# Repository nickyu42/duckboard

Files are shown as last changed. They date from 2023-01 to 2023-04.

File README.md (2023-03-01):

# Duckboard

This repository contains the PCB design for a 4x4 macroboard with a rotary encoder.  





## Fusion360 Model and Case





## Schematic



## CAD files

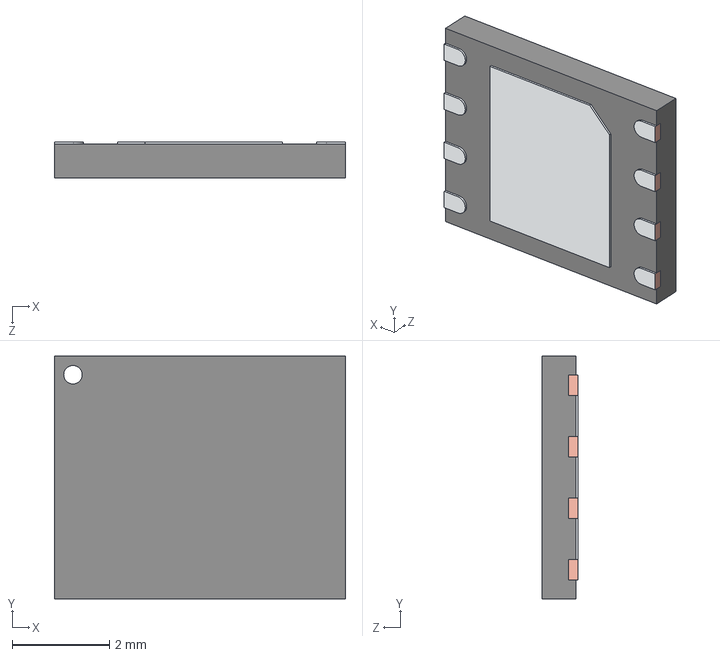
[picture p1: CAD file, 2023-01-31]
pcb/3D/User Library-8 WSON.STEP
6.00 x 5.00 x 0.75 mm

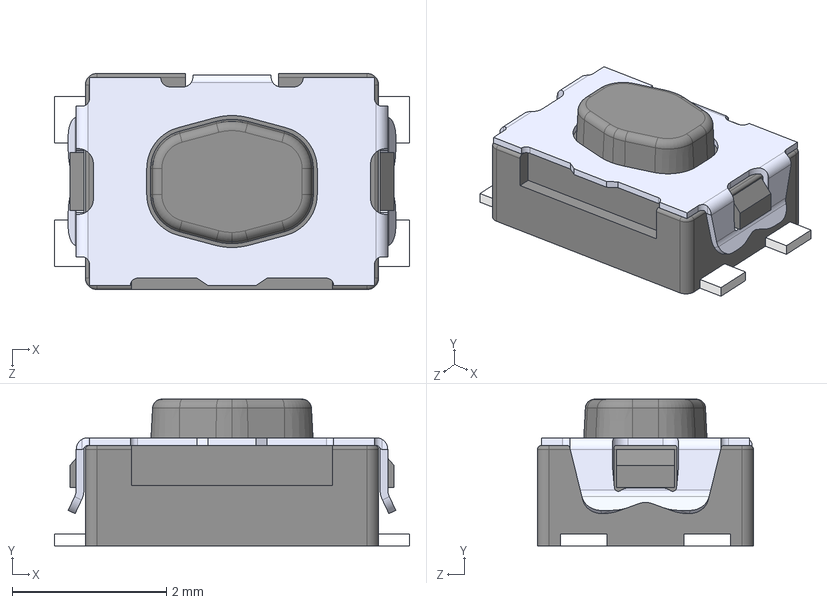
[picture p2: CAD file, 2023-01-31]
pcb/footprints/KMR221GLFS/KMR221GLFS.step
4.60 x 1.90 x 2.80 mm

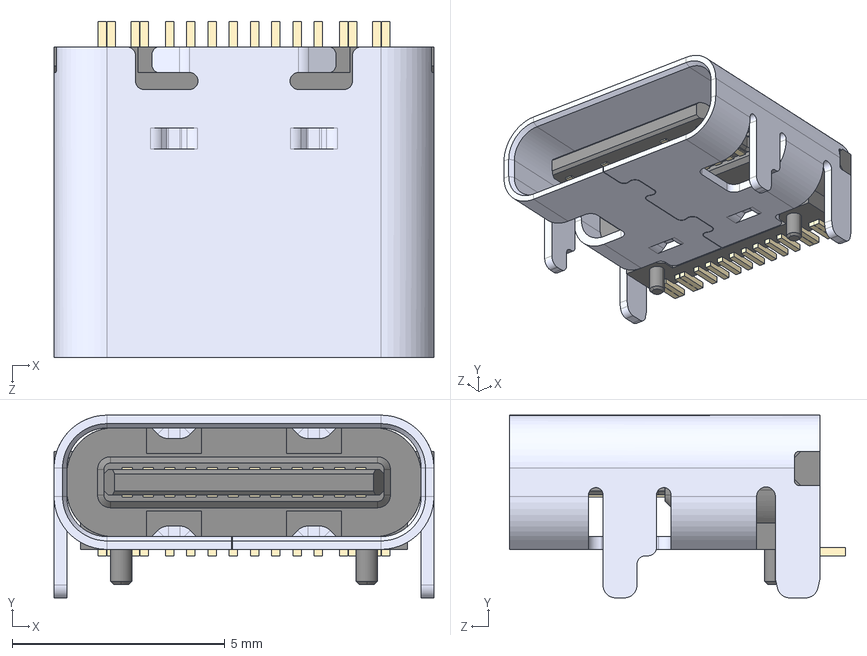
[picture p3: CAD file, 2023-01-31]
pcb/footprints/TYPE-C-31-M-12/TYPE-C-31-M-12.step
8.94 x 4.30 x 7.90 mm

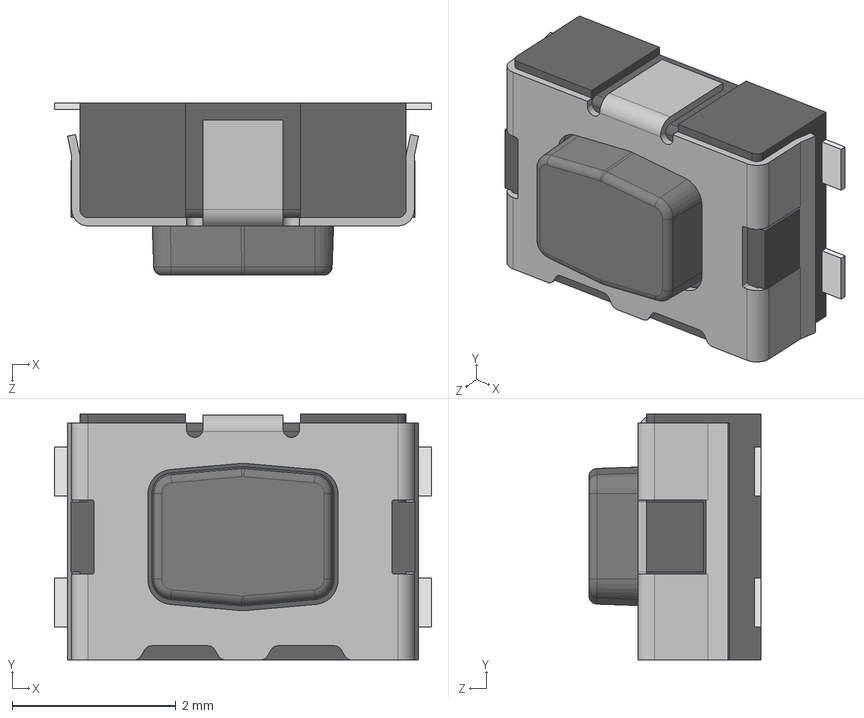
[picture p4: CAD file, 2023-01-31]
pcb/3D/Switch-CK-KMR2.STEP
4.60 x 3.00 x 2.10 mm
Button
Boitier
Tole
Pads

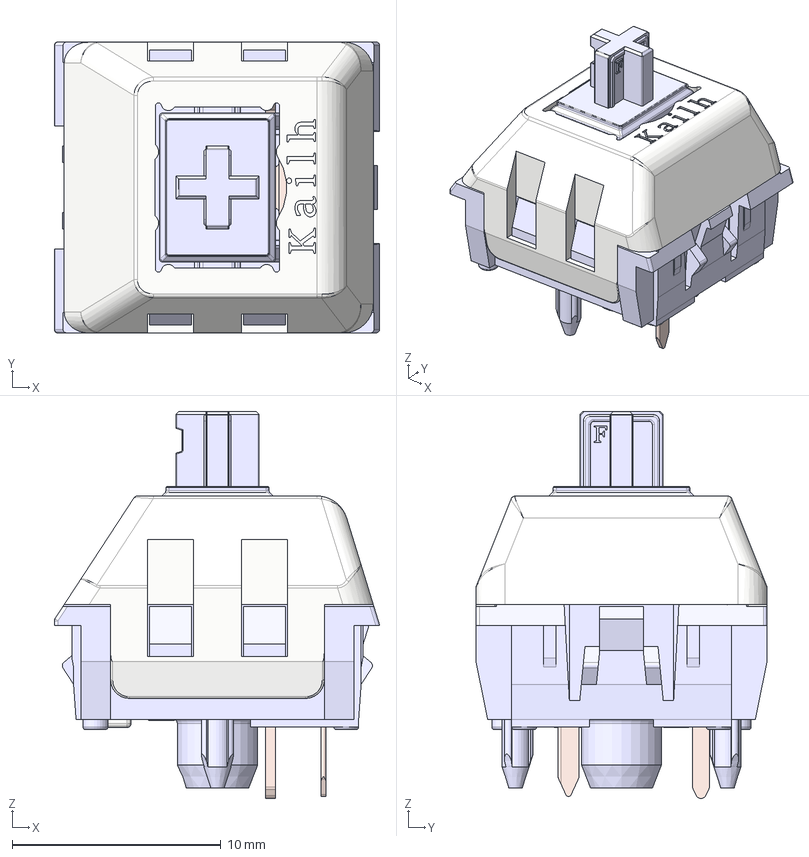
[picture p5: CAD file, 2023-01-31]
pcb/3D/Kailh Polia.step
15.6 x 14.0 x 18.5 mm
Housing
ThickContact
SpringContact
Stem
Lid

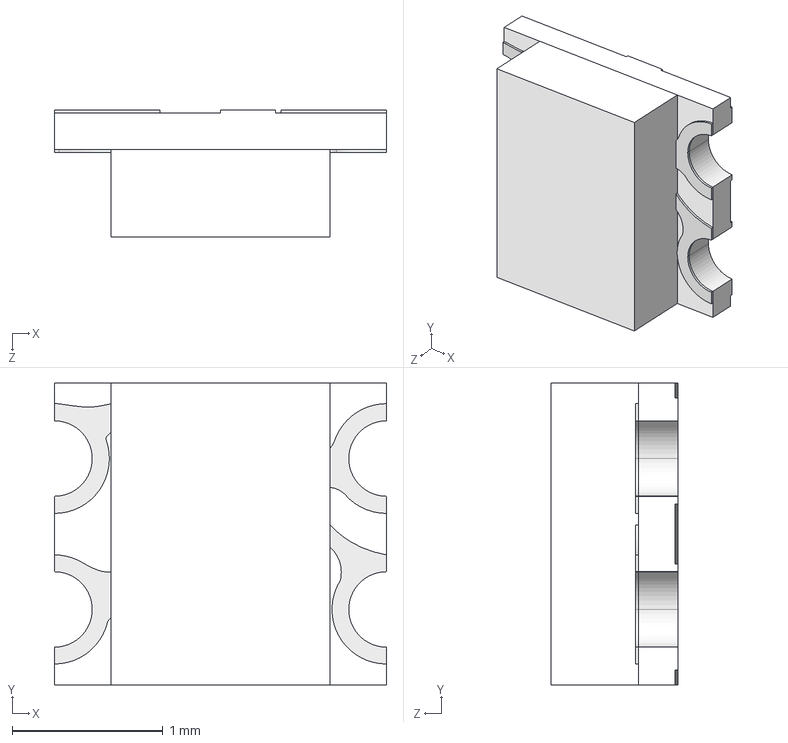
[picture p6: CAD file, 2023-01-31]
pcb/3D/User Library-WS2812-2020.STEP
2.20 x 2.00 x 0.84 mm

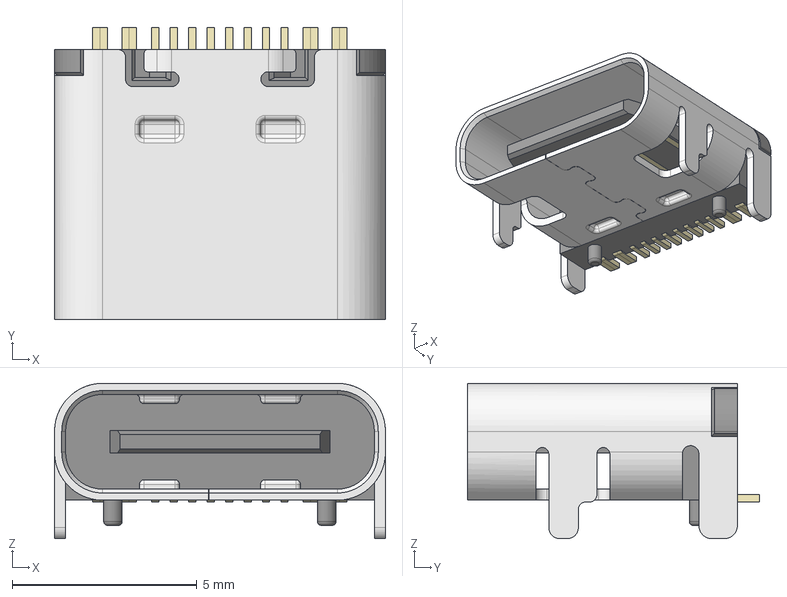
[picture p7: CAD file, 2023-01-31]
pcb/3D/HRO_TYPE-C-31-M-12.step
8.95 x 7.90 x 4.20 mm

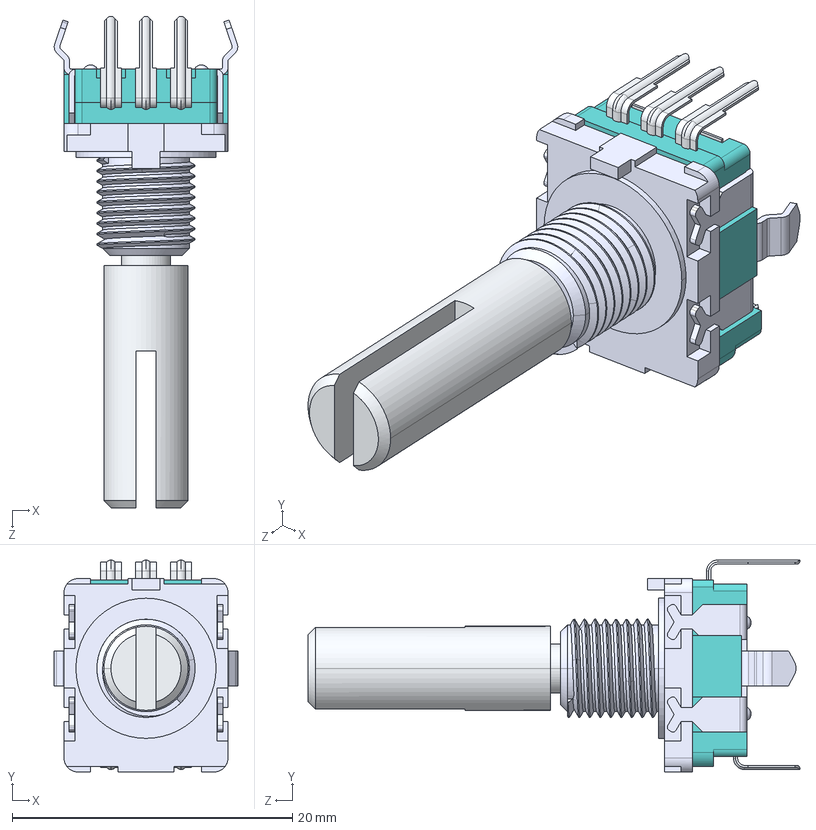
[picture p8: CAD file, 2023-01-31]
pcb/3D/User Library-EC11B15244.STEP
13.1 x 15.1 x 35.1 mm
Shaft
MetalBody
PlasticBody
Imported x 3
Pin x 2
Sheet Metal Part53

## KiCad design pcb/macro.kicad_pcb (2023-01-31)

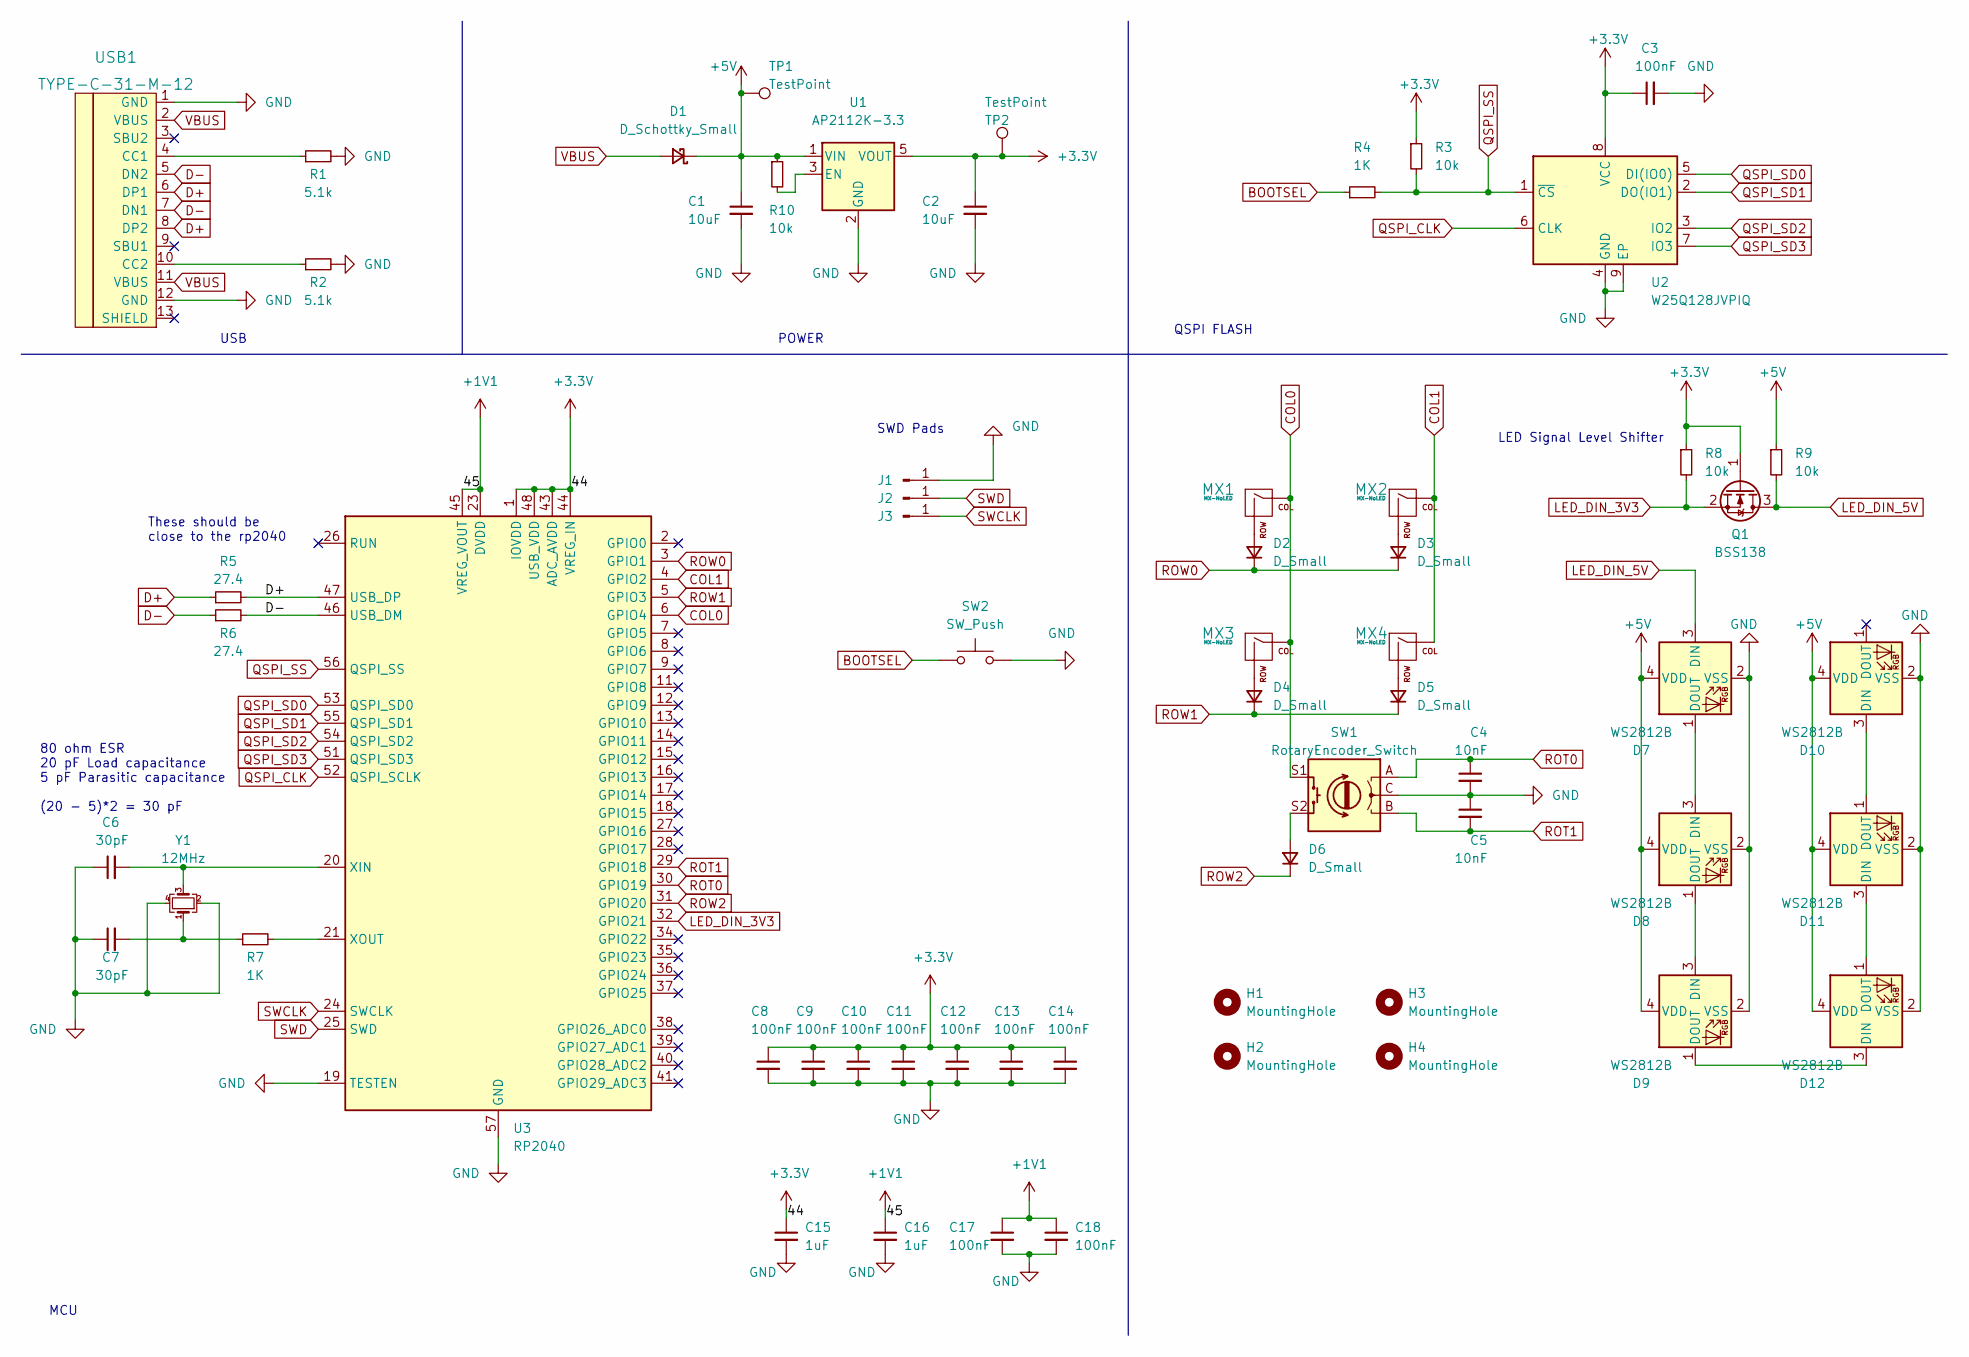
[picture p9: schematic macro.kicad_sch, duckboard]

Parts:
C1, C2: 10uF; C_0402_1005Metric
C3, C8, C9, C10, C11, C12, C13, C14, C17, C18: 100nF; C_0402_1005Metric
C4, C5: 10nF; C_0402_1005Metric
C6, C7: 30pF; C_0402_1005Metric
C15, C16: 1uF; C_0402_1005Metric
D1: D_Schottky_Small; D_SOD-323
D2, D3, D4, D5, D6: D_Small; D_SOD-323
D7, D8, D9, D10, D11, D12: WS2812B; LED_WS2812B-2020_PLCC4_2.0x2.0mm
H1, H2, H3, H4: MountingHole; MountingHole_2.2mm_M2
J1, J2, J3: Conn_01x01_Male; TestPoint_Pad_2.0x2.0mm
MX1, MX2, MX3, MX4: MX-NoLED; MX-1U-NoLED
Q1: BSS138; SOT-23
R1, R2: 5.1k; R_0402_1005Metric
R3, R8, R9, R10: 10k; R_0402_1005Metric
R4, R7: 1K; R_0402_1005Metric
R5, R6: 27.4; R_0402_1005Metric
SW1: RotaryEncoder_Switch; RotaryEncoder_Alps_EC11E-Switch_Vertical_H20mm_CircularMoun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
SW2: SW_Push; SW_KMR221GLFS
TP1, TP2: TestPoint; TestPoint_Pad_D1.0mm
U1: AP2112K-3.3; SOT-23-5
U2: W25Q128JVPIQ; WSON-8-1EP_6x5mm_P1.27mm_EP3.4x4.3mm
U3: RP2040; QFN-56-1EP_7x7mm_P0.4mm_EP3.2x3.2mm
USB1: TYPE-C-31-M-12; HRO_TYPE-C-31-M-12
Y1: 12MHz; Crystal_SMD_3225-4Pin_3.2x2.5mm

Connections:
+1V1: C16.1, C17.1, C18.1, U3.23 (DVDD), U3.45 (VREG_VOUT), U3.50 (DVDD)
+3.3V: C2.1, C3.1, C8.1, C9.1, C10.1, C11.1, C12.1, C13.1, C14.1, C15.1, Q1.1 (G), R3.1, R8.1, TP2.1, U1.5 (VOUT), U2.8 (VCC), U3.1 (IOVDD), U3.10 (IOVDD), U3.22 (IOVDD), U3.33 (IOVDD), U3.42 (IOVDD), U3.43 (ADC_AVDD), U3.44 (VREG_IN), U3.48 (USB_VDD), U3.49 (IOVDD)
+5V: C1.1, D1.1 (K), D7.4 (VDD), D8.4 (VDD), D9.4 (VDD), D10.4 (VDD), D11.4 (VDD), D12.4 (VDD), R9.1, R10.1, TP1.1, U1.1 (VIN)
BOOTSEL: R4.1, SW2.1
COL0: MX1.1 (COL), MX3.1 (COL), SW1.S1, U3.6 (GPIO4)
COL1: MX2.1 (COL), MX4.1 (COL), U3.4 (GPIO2)
D+: R5.1, R5.2, U3.47 (USB_DP), USB1.6 (DP1), USB1.8 (DP2)
D-: R6.1, R6.2, U3.46 (USB_DM), USB1.5 (DN2), USB1.7 (DN1)
GND: C1.2, C2.2, C3.2, C4.2, C5.1, C6.1, C7.1, C8.2, C9.2, C10.2, C11.2, C12.2, C13.2, C14.2, C15.2, C16.2, C17.2, C18.2, D7.2 (VSS), D8.2 (VSS), D9.2 (VSS), D10.2 (VSS), D11.2 (VSS), D12.2 (VSS), J1.1, R1.2, R2.2, SW1.C, SW2.2, SW2.5, U1.2 (GND), U2.4 (GND), U2.9 (EP), U3.19 (TESTEN), U3.57 (GND), USB1.1 (GND), USB1.12 (GND), Y1.2, Y1.4
LED_DIN_3V3: Q1.2 (S), R8.2, U3.32 (GPIO21)
LED_DIN_5V: D7.3 (DIN), Q1.3 (D), R9.2
unnamed: C6.2, U3.20 (XIN), Y1.3
unnamed: C7.2, R7.1, Y1.1
unnamed: D2.2 (A), MX1.2 (ROW)
unnamed: D3.2 (A), MX2.2 (ROW)
unnamed: D4.2 (A), MX3.2 (ROW)
unnamed: D5.2 (A), MX4.2 (ROW)
unnamed: D6.2 (A), SW1.S2
unnamed: D7.1 (DOUT), D8.3 (DIN)
unnamed: D8.1 (DOUT), D9.3 (DIN)
unnamed: D10.3 (DIN), D11.1 (DOUT)
unnamed: D11.3 (DIN), D12.1 (DOUT)
unnamed: D9.1 (DOUT), D12.3 (DIN)
unnamed: R1.1, USB1.4 (CC1)
unnamed: R2.1, USB1.10 (CC2)
unnamed: R7.2, U3.21 (XOUT)
unnamed: R10.2, U1.3 (EN)
QSPI_CLK: U2.6 (CLK), U3.52 (QSPI_SCLK)
QSPI_SD0: U2.5 (DI(IO0)), U3.53 (QSPI_SD0)
QSPI_SD1: U2.2 (DO(IO1)), U3.55 (QSPI_SD1)
QSPI_SD2: U2.3 (IO2), U3.54 (QSPI_SD2)
QSPI_SD3: U2.7 (IO3), U3.51 (QSPI_SD3)
QSPI_SS: R3.2, R4.2, U2.1 (~CS), U3.56 (QSPI_SS)
ROT0: C4.1, SW1.A, U3.30 (GPIO19)
ROT1: C5.2, SW1.B, U3.29 (GPIO18)
ROW0: D2.1 (K), D3.1 (K), U3.3 (GPIO1)
ROW1: D4.1 (K), D5.1 (K), U3.5 (GPIO3)
ROW2: D6.1 (K), U3.31 (GPIO20)
SWCLK: J3.1, U3.24 (SWCLK)
SWD: J2.1, U3.25 (SWD)
VBUS: D1.2 (A), USB1.2 (VBUS), USB1.11 (VBUS)

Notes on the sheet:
These should be close to the rp2040
LED Signal Level Shifter
SWD Pads
80 ohm ESR 20 pF Load capacitance 5 pF Parasitic capacitance (20 - 5)*2 = 30 pF
POWER
QSPI FLASH
USB
MCU

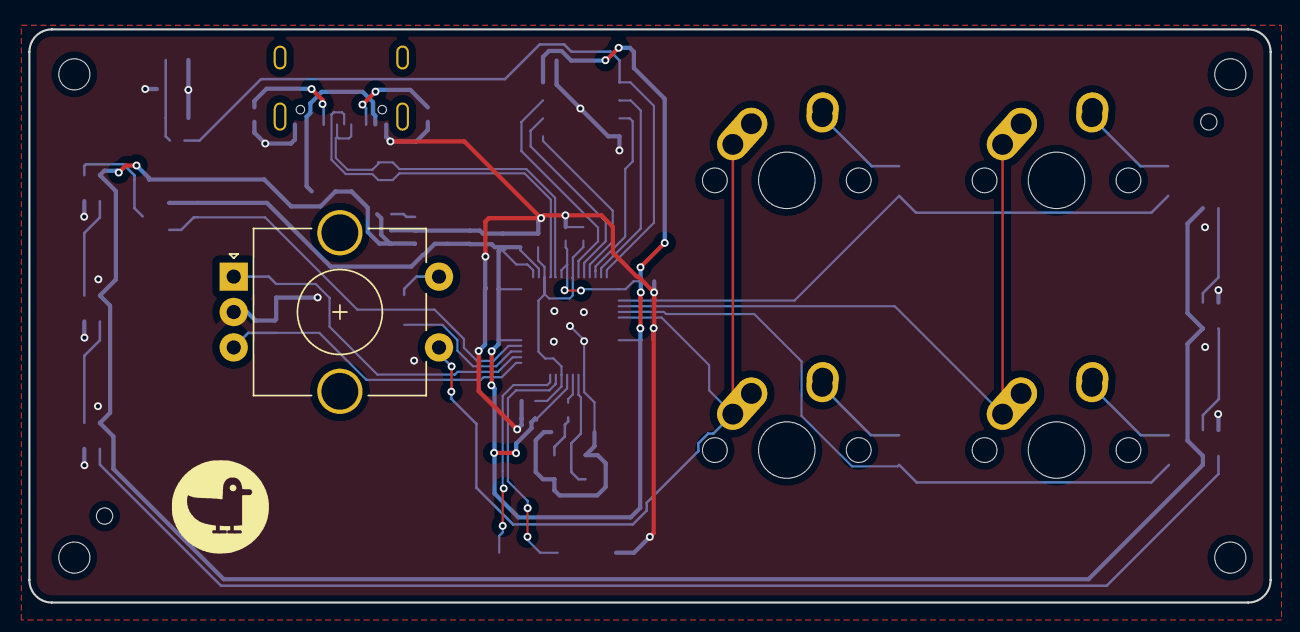
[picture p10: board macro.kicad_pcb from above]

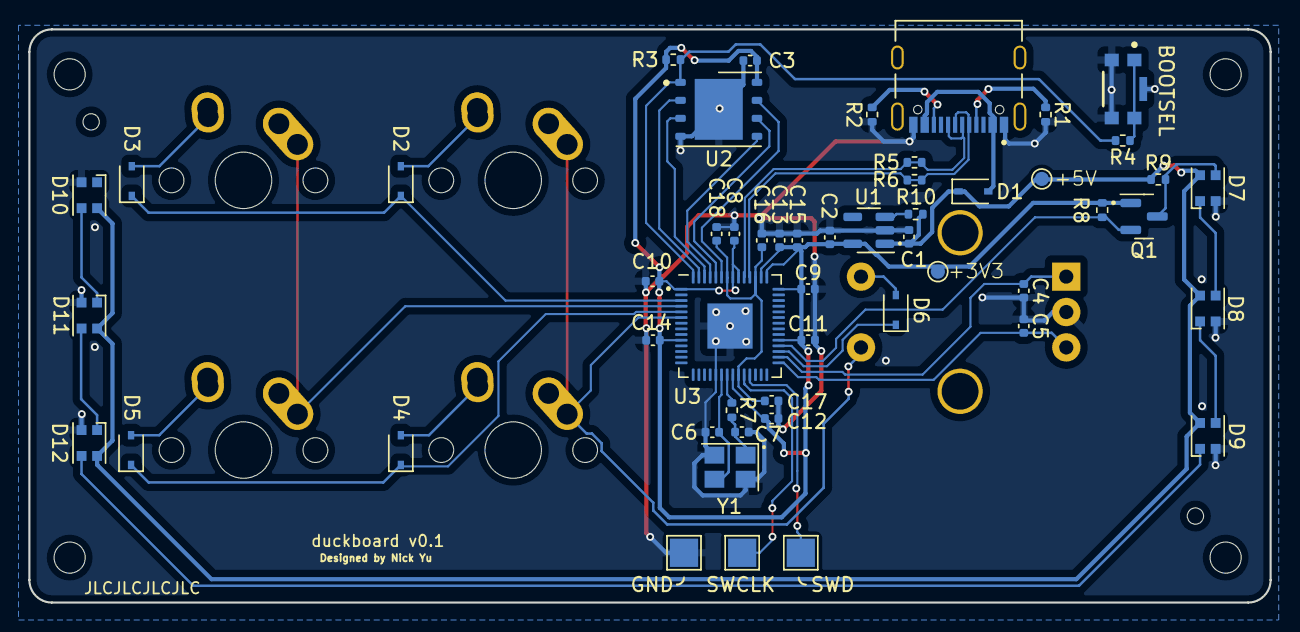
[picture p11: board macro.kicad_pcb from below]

Board: 2 copper layers, 87.7 x 40.5 mm, 61 parts (52 on the bottom side), 41 nets.

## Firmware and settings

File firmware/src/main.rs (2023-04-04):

#![no_std]
#![no_main]
#![feature(let_chains)]

// Handle panicking with probe-run
use panic_probe as _;

use rtic;

mod board_config;
mod key_mapping;
mod keyboard_matrix;
mod rotary_encoder;

#[rtic::app(device = rp2040_hal::pac, peripherals = true, dispatchers = [TIMER_IRQ_1])]
mod app {
    use rp2040_hal::{self as hal, usb::UsbBus};

    // Setup defmt with RTT
    use defmt::*;
    use defmt_rtt as _;

    use fugit::ExtU32;

    use hal::{clocks::init_clocks_and_plls, pio::PIOExt, sio::Sio, watchdog::Watchdog, Clock};

    use rp2040_hal::timer::Alarm0;

    use usb_device::class_prelude::UsbBusAllocator;
    use usb_device::prelude::{UsbDevice, UsbDeviceBuilder, UsbVidPid};
    use usbd_human_interface_device::device::keyboard::NKROBootKeyboardInterface;
    use usbd_human_interface_device::page::Keyboard;
    use usbd_human_interface_device::prelude::*;

    use cichlid::{prelude::*, ColorRGB};
    use smart_leds::{SmartLedsWrite, RGB8};
    use ws2812_pio::Ws2812Direct;

    use crate::key_mapping::encoder_mapping;
    use crate::{board_config, keyboard_matrix, rotary_encoder};

    #[shared]
    struct Shared {
        // hid: hid_class::HIDClass<'static, UsbBus>,
        hid: UsbHidClass<UsbBus, frunk::HList!(NKROBootKeyboardInterface<'static, UsbBus>)>,

        ws: Ws2812Direct<hal::pac::PIO0, hal::pio::SM0, hal::gpio::bank0::Gpio21>,
    }

    #[local]
    struct Local {
        matrix: keyboard_matrix::KeyboardMatrix,
        encoder: rotary_encoder::RotaryEncoder<hal::gpio::bank0::Gpio19, hal::gpio::bank0::Gpio18>,
        usb_dev: UsbDevice<'static, UsbBus>,
    }

    #[monotonic(binds = TIMER_IRQ_0, default = true)]
    type Monotonic = rp2040_hal::timer::monotonic::Monotonic<Alarm0>;

    #[init(local = [usb_bus: Option<usb_device::bus::UsbBusAllocator<hal::usb::UsbBus>> = None])]
    fn init(mut cx: init::Context) -> (Shared, Local, init::Monotonics) {
        // Soft-reset does not release the hardware spinlocks
        // Release them now to avoid a deadlock after debug or watchdog reset
        unsafe {
            hal::sio::spinlock_reset();
        }

        info!("Hello from duckboard");

        let mut watchdog = Watchdog::new(cx.device.WATCHDOG);
        let sio = Sio::new(cx.device.SIO);

        let clocks = init_clocks_and_plls(
            super::board_config::XOSC_CRYSTAL_FREQ,
            cx.device.XOSC,
            cx.device.CLOCKS,
            cx.device.PLL_SYS,
            cx.device.PLL_USB,
            &mut cx.device.RESETS,
            &mut watchdog,
        )
        .ok()
        .unwrap();

        info!("Setting up peripherals");

        // Setup input peripherals
        let pins = board_config::Pins::new(
            cx.device.IO_BANK0,
            cx.device.PADS_BANK0,
            sio.gpio_bank0,
            &mut cx.device.RESETS,
        );

        let matrix = keyboard_matrix::KeyboardMatrix::new(
            [pins.row0.into(), pins.row1.into(), pins.row2.into()],
            [pins.col0.into(), pins.col1.into()],
        );

        let encoder = rotary_encoder::RotaryEncoder::new(
            pins.rot0.into_readable_output(),
            pins.rot1.into_readable_output(),
        );

        let (mut pio, sm0, _, _, _) = cx.device.PIO0.split(&mut cx.device.RESETS);
        let ws = Ws2812Direct::new(
            pins.led_out.into_mode(),
            &mut pio,
            sm0,
            clocks.peripheral_clock.freq(),
        );

        info!("Setting up USB");

        // Setup USB device and HID handler
        let usb_bus: &'static _ = cx.local.usb_bus.insert(UsbBusAllocator::new(UsbBus::new(
            cx.device.USBCTRL_REGS,
            cx.device.USBCTRL_DPRAM,
            clocks.usb_clock,
            true,
            &mut cx.device.RESETS,
        )));

        let hid = UsbHidClassBuilder::new()
            .add_interface(NKROBootKeyboardInterface::default_config())
            .build(&usb_bus);

        let vid_pid = UsbVidPid(0x1209, 0x0001);
        let usb_dev = UsbDeviceBuilder::new(&usb_bus, vid_pid)
            .manufacturer("Compubotics")
            .product("Duckboard")
            .serial_number("DCK001")
            .build();

        info!("Spawning monotonic tasks");

        // Setup timer for tasks
        let mut timer = hal::Timer::new(cx.device.TIMER, &mut cx.device.RESETS);
        let alarm = timer.alarm_0().unwrap();
        let mono = hal::timer::monotonic::Monotonic::new(timer, alarm);

        poll_inputs::spawn().unwrap();
        tick::spawn().unwrap();
        led_pattern::spawn().unwrap();

        info!("Init done! :)");

        (
            Shared { hid, ws },
            Local {
                matrix,
                encoder,
                usb_dev,
            },
            init::Monotonics(mono),
        )
    }

    #[task(local = [encoder, matrix], shared = [hid])]
    fn poll_inputs(mut cx: poll_inputs::Context) {
        let mut report: [Keyboard; 6] = [Keyboard::NoEventIndicated; 6];

        if let Ok(scan_result) = cx.local.matrix.scan() && scan_result.should_report()
        {
            if scan_result.event_occurred {
                debug!("{:?}", cx.local.matrix);
            }

            let keys = cx.local.matrix.get_pressed_keys();

            for i in 0..5 {
                report[i] = keys[i];
            }
        };

        if let Some(r) = cx.local.encoder.read() {
            debug!("{:?}", r);

            report[5] = encoder_mapping(r);
        }

        cx.shared.hid.lock(|hid| {
            while let Err(UsbHidError::WouldBlock) = hid.interface().write_report(report) {
                debug!("HID write blocking");
            }
        });

        poll_inputs::spawn_at(monotonics::now() + 5_u32.millis()).unwrap();
    }

    #[task(shared = [hid])]
    fn tick(mut cx: tick::Context) {
        cx.shared.hid.lock(|k| match k.interface().tick() {
            Err(UsbHidError::WouldBlock) => {}
            Ok(_) => {}
            Err(e) => {
                core::panic!("Failed to process hid tick: {:?}", e)
            }
        });

        tick::spawn_at(monotonics::now() + 1_u32.millis()).unwrap();
    }

    #[task(shared = [ws], local = [start_hue: u8 = 0])]
    fn led_pattern(mut cx: led_pattern::Context) {
        let start_hue = *cx.local.start_hue;

        *cx.local.start_hue = if start_hue == 255 { 0 } else { start_hue + 1 };

        let mut colors = [ColorRGB::Black; 6];
        let hue_delta: u16 = 1 << 12;

        colors.rainbow_fill(*cx.local.start_hue, hue_delta);

        cx.shared.ws.lock(|ws| {
            ws.write(colors.iter().map(|c| RGB8 {
                r: c.r,
                g: c.g,
                b: c.b,
            }))
            .unwrap();
        });

        led_pattern::spawn_at(monotonics::now() + 10_u32.millis()).unwrap();
    }

    #[task(binds = USBCTRL_IRQ, priority = 3, local = [usb_dev], shared = [hid])]
    fn usb_rx(mut cx: usb_rx::Context) {
        cx.shared.hid.lock(|hid| {
            // Poll USB device
            if cx.local.usb_dev.poll(&mut [hid]) {
                hid.interface().read_report().ok();
            }
        });
    }

    #[idle]
    fn idle(_: idle::Context) -> ! {
        loop {
            cortex_m::asm::nop();
        }
    }
}

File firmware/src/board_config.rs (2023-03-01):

use rp2040_hal as hal;

#[link_section = ".boot2"]
#[no_mangle]
#[used]
static BOOT2_FIRMWARE: [u8; 256] = rp2040_boot2::BOOT_LOADER_W25Q080;

hal::bsp_pins!(
    Gpio1 { name: row0 },
    Gpio2 { name: col1 },
    Gpio3 { name: row1 },
    Gpio4 { name: col0 },
    Gpio18 { name: rot1 },
    Gpio19 { name: rot0 },
    Gpio20 { name: row2 },
    Gpio21 { name: led_out },
);

pub const XOSC_CRYSTAL_FREQ: u32 = 12_000_000;

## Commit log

2022-10-25 Add ws2812
    [macro-B_Cu.gbr, macro-B_Mask.gbr, macro-B_Paste.gbr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]
2022-12-27 New design
    [macro.kicad_pcb, macro.kicad_sch]
2022-12-27 Rough placement
    [macro.kicad_pcb, macro.kicad_sch]
2022-12-29 Cleanup schematic
    [macro.kicad_pcb, macro.kicad_sch]
2022-12-29 Add LED decoupling caps
    [macro-B_Cu.gbr, macro-B_Mask.gbr, macro-B_Paste.gbr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]
2023-01-07 Add tooling holes and logo
    [macro.kicad_pcb, macro.kicad_sch]
2023-01-07 V0.1 Version
    [macro.kicad_pcb, macro.kicad_sch]
2023-01-11 Drill hole center
    [macro-B_Cu.gbr, macro-B_Mask.gbr, macro-B_Paste.gbr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]
2023-01-31 Add 3D models used
    [HRO_TYPE-C-31-M-12.step, KMR221GLFS.step, Kailh Polia.step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]
2023-01-31 Move to pcb folder
    [HRO_TYPE-C-31-M-12.step, KMR221GLFS.step, Kailh Polia.step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]
2023-01-31 Move footprints
    [KMR221GLFS.step, TYPE-C-31-M-12.step, macro.kicad_pcb]
2023-03-13 Add cichlid and basic LED pattern
